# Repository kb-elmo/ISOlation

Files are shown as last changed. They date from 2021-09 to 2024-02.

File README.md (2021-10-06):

# ISOlation

[][cc-by-nc-sa]<a href="https://ko-fi.com/kb_elmo">kofibadge</a>

### A seamless ISO single-key "macropad"
#### Stupid things I come up with during Covid isolation...

header

---

[STEP files for the case](case/)

[KiCAD PCB files](pcb/)

[Gerbers for PCB production](pcb/gerbers/)

[JLCPCB BOM](pcb/fab/iso_bom_jlc.csv)

[JLCPCB CPL](pcb/fab/iso_cpl_jlc.csv)

[Vial-QMK firmware](firmware/)

---

This work is licensed under a
[Creative Commons Attribution-NonCommercial-ShareAlike 4.0 International License][cc-by-nc-sa].

[][cc-by-nc-sa]

[cc-by-nc-sa]: http://creativecommons.org/licenses/by-nc-sa/4.0/
[cc-by-nc-sa-image]: https://licensebuttons.net/l/by-nc-sa/4.0/88x31.png
[cc-by-nc-sa-shield]: https://img.shields.io/badge/License-CC%20BY--NC--SA%204.0-lightgrey.svg

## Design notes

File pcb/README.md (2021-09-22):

# ISOlation PCB

### Features

- Full key and stabilizer RGB
- Screw-in stabilizer support
- Powered by an Atmega328p
- Basic ESD and overvoltage protection
- Centered USB type-C port for a detachable cable
- Fully programmable using [QMK](https://qmk.fm) and [Vial](https://get.vial.today)

---

### Preview

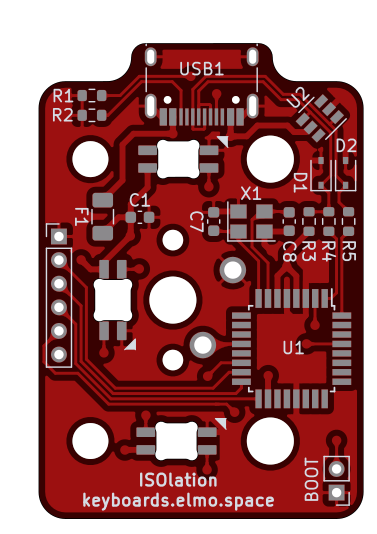
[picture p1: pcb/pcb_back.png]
pcb_back
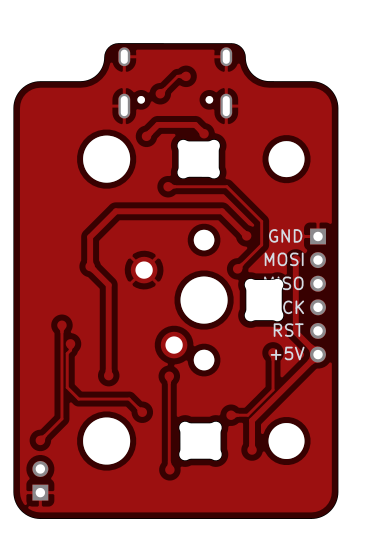
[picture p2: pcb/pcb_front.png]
pcb_front


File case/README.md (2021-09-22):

# ISOlation case

### These files are meant for 3D printing only! 

They are not suitable for CNC machining and trying to use them for that will most likely result in failure of the parts.

The top piece should be printed upside down with supports for the integrated plate to get the best looking results.  
The bottom can be printed without any supports in it's natural orientation.

The bottom part is a simple friction fit into the top.  
Make sure that everything works and is installed properly on the PCB when putting the case together.  
Removing the bottom piece later is not really easy.

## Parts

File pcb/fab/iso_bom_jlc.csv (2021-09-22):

Comment | Designator | Footprint | LCSC Part #
10uF | C1 | C_0603_1608Metric | C19702
22pF | C7,C8 | C_0603_1608Metric | C1653
D_Zener_Small | D2,D1 | D_SOD-323 | C401091
Polyfuse_Small | F1 | Fuse_1206_3216Metric | C69688
5.1k | R1,R2 | R_0603_1608Metric | C23186
1.5K | R3 | R_0603_1608Metric | C22843
68R | R4,R5 | R_0603_1608Metric | C27592
ATmega328P-AU | U1 | TQFP-32_7x7mm_P0.8mm | C14877
SRV05-4 | U2 | SOT-23-6 | C85364
USB_C_Receptacle_USB2.0 | USB1 | USB_C_Receptacle_HRO_TYPE-C-31-M-12 | C165948
Crystal_GND24_Small | X1 | Crystal_SMD_3225-4Pin_3.2x2.5mm | C13738

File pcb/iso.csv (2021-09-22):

Comment | Designator | Footprint | LCSC
SW_Push | BOOT1 | Connector_PinHeader_2.00mm:PinHeader_1x02_P2.00mm_Vertical
10uF | C1 | Capacitor_SMD:C_0603_1608Metric | C19702
22pF | C7,C8 | Capacitor_SMD:C_0603_1608Metric | C1653
D_Zener_Small | D1,D2 | Diode_SMD:D_SOD-323 | C401091
Polyfuse_Small | F1 | Fuse:Fuse_1206_3216Metric | C69688
Conn_01x06 | J1 | Connector_PinHeader_2.00mm:PinHeader_1x06_P2.00mm_Vertical
SK6812MINI | LED1,LED2,LED3 | custom_parts:SK6812MINIE-simple
MX-NoLED | MX1 | custom_parts:MXOnly-ISO-ROTATEDCCW-ReversedStabilizers-NoLED
5.1k | R1,R2 | Resistor_SMD:R_0603_1608Metric | C23186
1.5K | R3 | Resistor_SMD:R_0603_1608Metric | C22843
68R | R4,R5 | Resistor_SMD:R_0603_1608Metric | C27592
ATmega328P-AU | U1 | Package_QFP:TQFP-32_7x7mm_P0.8mm | C14877
SRV05-4 | U2 | Package_TO_SOT_SMD:SOT-23-6 | C85364
USB_C_Receptacle_USB2.0 | USB1 | Connector_USB:USB_C_Receptacle_HRO_TYPE-C-31-M-12 | C165948
Crystal_GND24_Small | X1 | Crystal:Crystal_SMD_3225-4Pin_3.2x2.5mm | C13738

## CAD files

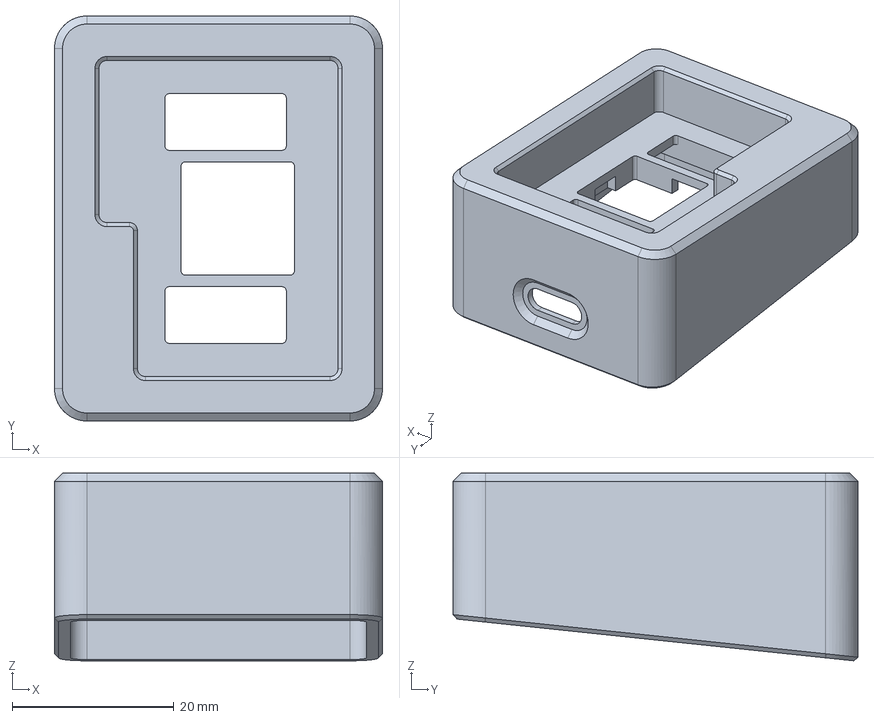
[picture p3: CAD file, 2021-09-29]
case/top.step
40.6 x 50.1 x 23.2 mm

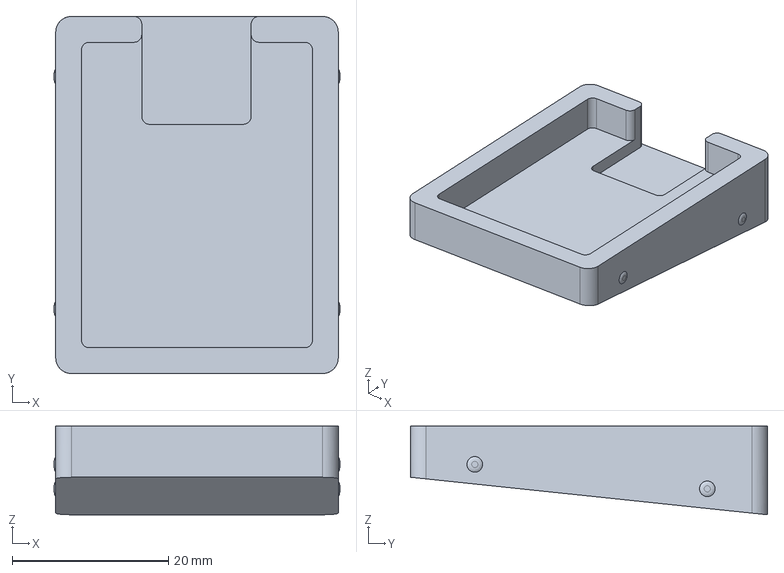
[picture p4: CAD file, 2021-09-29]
case/bottom.step
36.6 x 45.7 x 11.3 mm

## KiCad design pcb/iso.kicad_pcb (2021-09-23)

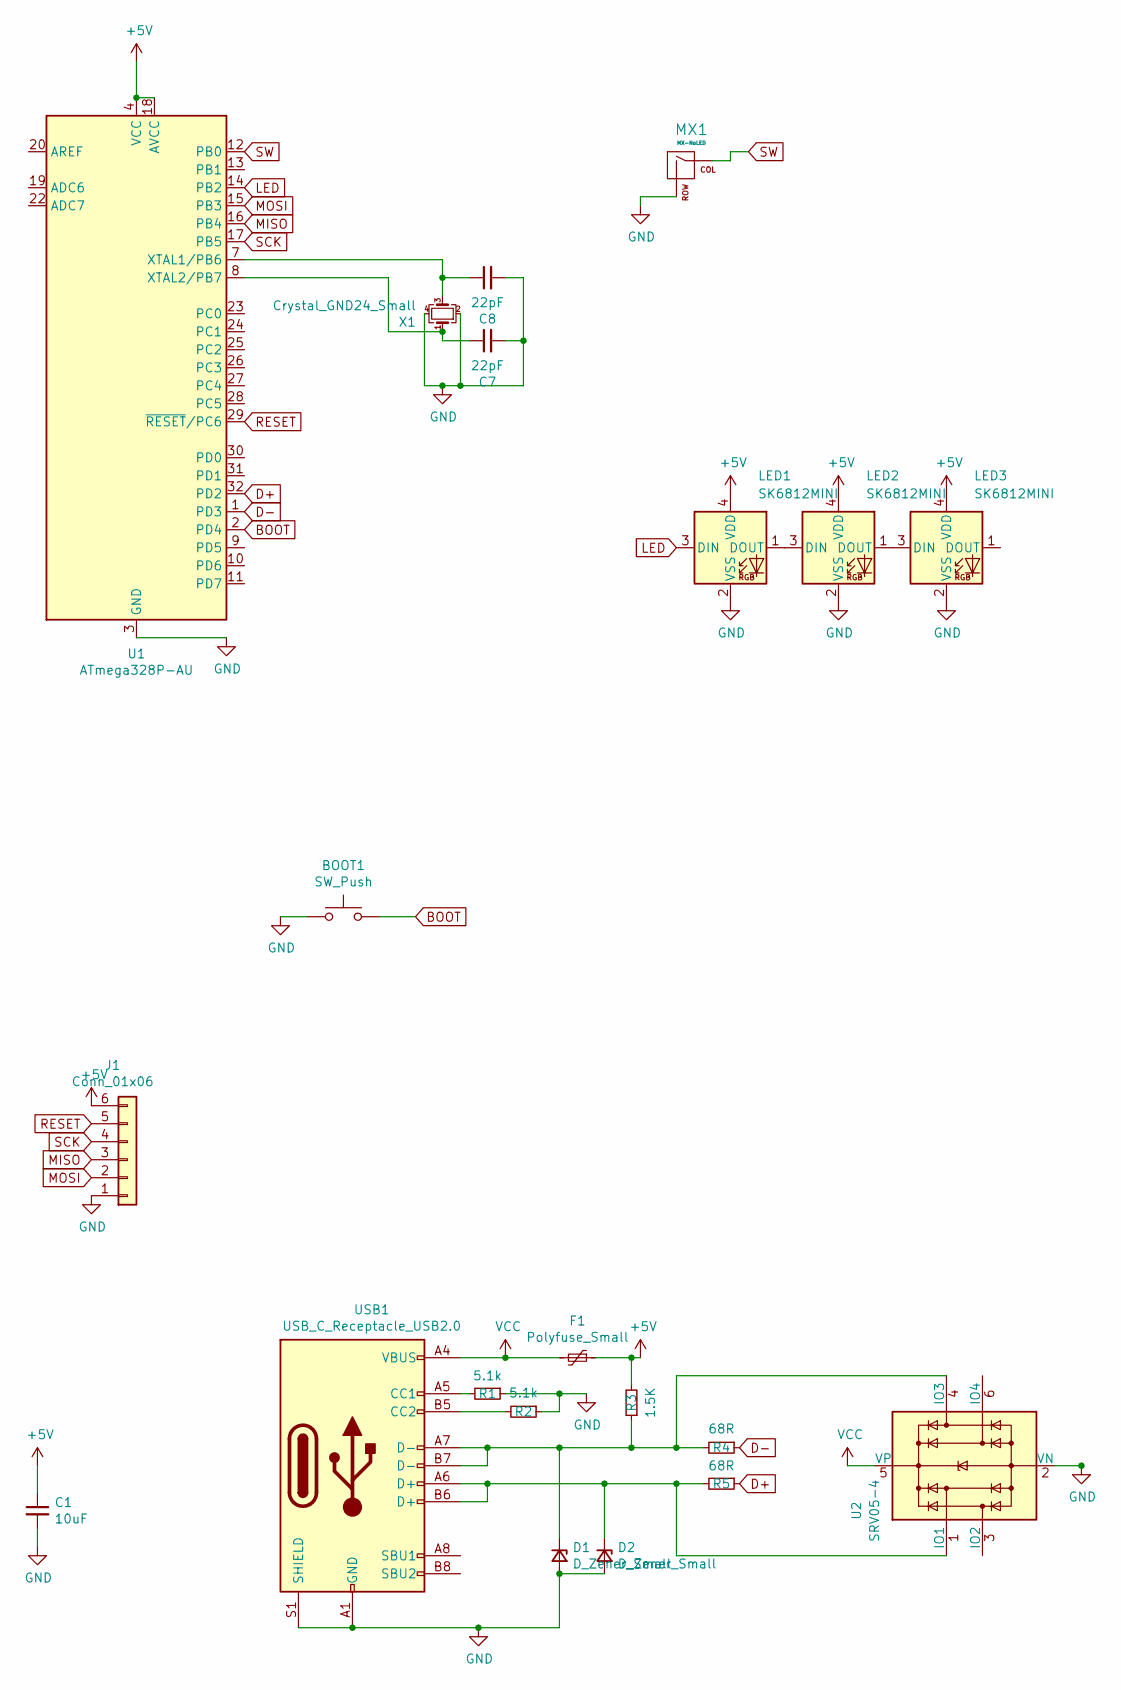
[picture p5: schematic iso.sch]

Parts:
BOOT1: SW_Push; PinHeader_1x02_P2.00mm_Vertical
C1: 10uF; C_0603_1608Metric; LCSC C19702
C7, C8: 22pF; C_0603_1608Metric; LCSC C1653
D1, D2: D_Zener_Small; D_SOD-323; LCSC C401091
F1: Polyfuse_Small; Fuse_1206_3216Metric; LCSC C69688
J1: Conn_01x06; PinHeader_1x06_P2.00mm_Vertical
LED1, LED2, LED3: SK6812MINI; SK6812MINIE-simple
MX1: MX-NoLED; MXOnly-ISO-ROTATEDCCW-ReversedStabilizers-NoLED
R1, R2: 5.1k; R_0603_1608Metric; LCSC C23186
R3: 1.5K; R_0603_1608Metric; LCSC C22843
R4, R5: 68R; R_0603_1608Metric; LCSC C27592
U1: ATmega328P-AU; TQFP-32_7x7mm_P0.8mm; LCSC C14877
U2: SRV05-4; SOT-23-6; LCSC C85364
USB1: USB_C_Receptacle_USB2.0; USB_C_Receptacle_HRO_TYPE-C-31-M-12; LCSC C165948
X1: Crystal_GND24_Small; Crystal_SMD_3225-4Pin_3.2x2.5mm; LCSC C13738

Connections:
+5V: C1.1, F1.1, J1.6, LED1.4 (VDD), LED2.4 (VDD), LED3.4 (VDD), R3.2, U1.4 (VCC), U1.6 (VCC), U1.18 (AVCC)
BOOT: BOOT1.2, U1.2 (PD4); also elsewhere on the board
D+: R5.1, U1.32 (PD2)
D-: R4.1, U1.1 (PD3)
GND: BOOT1.1, C1.2, C7.2, C8.2, D1.2 (A), D2.2 (A), J1.1, LED1.2 (VSS), LED2.2 (VSS), LED3.2 (VSS), MX1.2 (ROW), R1.1, R2.1, U1.3 (GND), U1.5 (GND), U1.21 (GND), U2.2 (VN), USB1.A1 (GND), USB1.A12 (GND), USB1.B1 (GND), USB1.B12 (GND), USB1.S1 (SHIELD), X1.2, X1.4; also elsewhere on the board
LED: LED1.3 (DIN), U1.14 (PB2)
MISO: J1.3, U1.16 (PB4)
MOSI: J1.2, U1.15 (PB3)
unnamed: C7.1, U1.8 (XTAL2/PB7), X1.1
unnamed: C8.1, U1.7 (XTAL1/PB6), X1.3
unnamed: D1.1 (K), R3.1, R4.2, U2.4 (IO3), USB1.A7 (D-), USB1.B7 (D-)
unnamed: D2.1 (K), R5.2, U2.1 (IO1), USB1.A6 (D+), USB1.B6 (D+)
unnamed: LED1.1 (DOUT), LED2.3 (DIN)
unnamed: LED2.1 (DOUT), LED3.3 (DIN)
unnamed: R1.2, USB1.A5 (CC1)
unnamed: R2.2, USB1.B5 (CC2)
RESET: J1.5, U1.29 (~RESET~/PC6)
SCK: J1.4, U1.17 (PB5)
SW: MX1.1 (COL), U1.12 (PB0)
VCC: F1.2, U2.5 (VP), USB1.A4 (VBUS), USB1.A9 (VBUS), USB1.B4 (VBUS), USB1.B9 (VBUS)

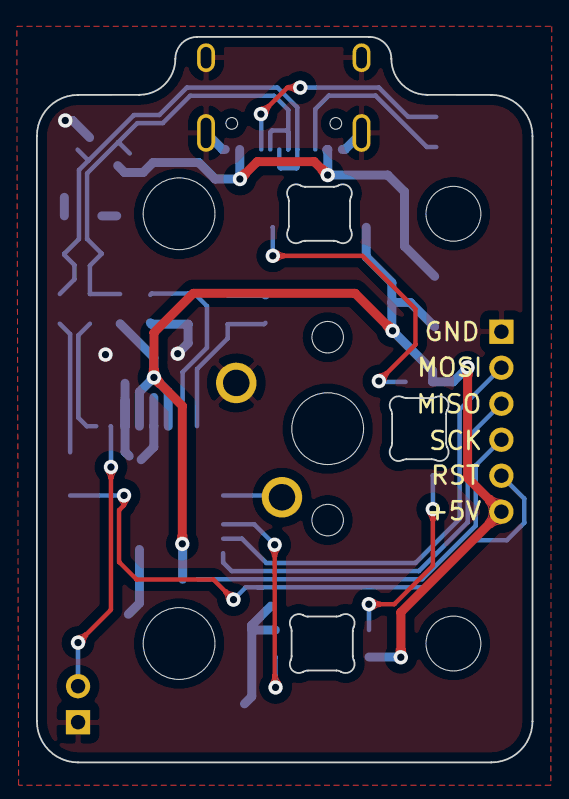
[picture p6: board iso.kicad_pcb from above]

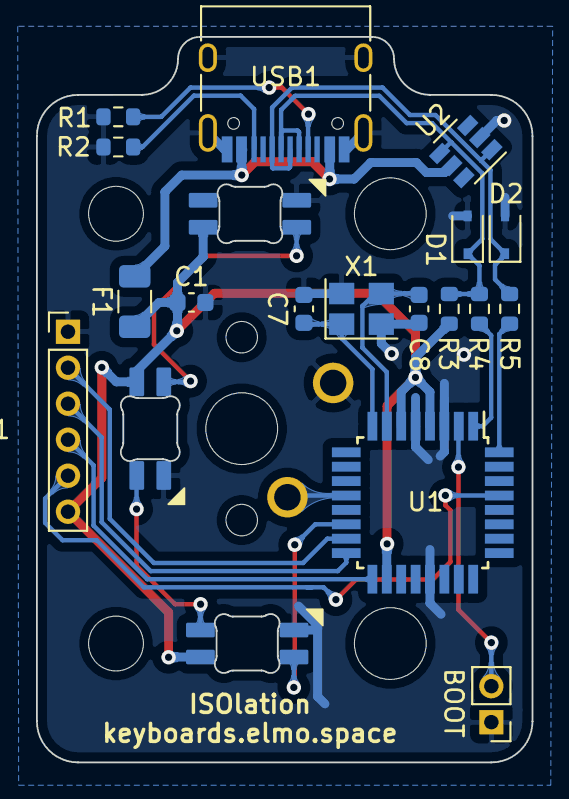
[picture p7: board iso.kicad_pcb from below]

Board: 2 copper layers, 27.5 x 40.3 mm, 21 parts (17 on the bottom side), 20 nets.

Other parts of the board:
BOOT: SW_Push; PinHeader_1x02_P2.00mm_Vertical

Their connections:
BOOT: BOOT.2; also elsewhere on the board
GND: BOOT.1; also elsewhere on the board

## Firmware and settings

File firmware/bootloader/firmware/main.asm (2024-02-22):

main.elf:     file format elf32-avr

SYMBOL TABLE:
00800100 l    d  .data	00000000 .data
00007000 l    d  .text	00000000 .text
00800106 l    d  .bss	00000000 .bss
0080013b l    d  .noinit	00000000 .noinit
00000000 l    d  .comment	00000000 .comment
00000000 l    d  .note.gnu.avr.deviceinfo	00000000 .note.gnu.avr.deviceinfo
00000000 l    d  .debug_aranges	00000000 .debug_aranges
00000000 l    d  .debug_info	00000000 .debug_info
00000000 l    d  .debug_abbrev	00000000 .debug_abbrev
00000000 l    d  .debug_line	00000000 .debug_line
00000000 l    d  .debug_frame	00000000 .debug_frame
00000000 l    d  .debug_str	00000000 .debug_str
00000000 l    d  .debug_line_str	00000000 .debug_line_str
00000000 l    d  .debug_loclists	00000000 .debug_loclists
00000000 l    d  .debug_macro	00000000 .debug_macro
00000000 l    d  .debug_rnglists	00000000 .debug_rnglists
00000000 l    df *ABS*	00000000 main.c
0000003e l       *ABS*	00000000 __SP_H__
0000003d l       *ABS*	00000000 __SP_L__
0000003f l       *ABS*	00000000 __SREG__
00000000 l       *ABS*	00000000 __tmp_reg__
00000001 l       *ABS*	00000000 __zero_reg__
000070e4 l       .text	00000000 .Loc.0
000070e4 l       .text	00000000 L0
000070e4 l       .text	00000000 .Loc.1
000070f4 l       .text	00000000 __BOOTLOADERENTRY_FROMSOFTWARE__bootup_investigate_RAMEND_done6
000070f2 l       .text	00000000 __BOOTLOADERENTRY_FROMSOFTWARE__bootup_investigate_RAMEND_mismatch6
0080013c l     O .noinit	00000001 __BOOTLOADERENTRY_FROMSOFTWARE__bootup_RAMEND_doesmatch
0080013b l     O .noinit	00000001 __BOOTLOADERENTRY_FROMSOFTWARE__bootup_MCUCSR
000070fc l       .text	00000000 .Loc.2
000070fc l       .text	00000000 L0
00007382 l       .text	00000000 .Loc.3
00007382 l       .text	00000000 L0
00007382 l       .text	00000000 .Loc.4
00007384 l       .text	00000000 .Loc.5
00007384 l       .text	00000000 .Loc.6
00007384 l       .text	00000000 .Loc.7
00007384 l       .text	00000000 .Loc.8
00007386 l       .text	00000000 .Loc.9
00007386 l       .text	00000000 .Loc.10
00007388 l       .text	00000000 .Loc.11
0000738c l       .text	00000000 .Loc.12
00007392 l       .text	00000000 .Loc.13
00007392 l       .text	00000000 .Loc.14
00007394 l       .text	00000000 .Loc.15
00007398 l       .text	00000000 .Loc.16
00007398 l       .text	00000000 .Loc.17
00007398 l       .text	00000000 .Loc.18
0000739a l       .text	00000000 .Loc.19
0000739c l       .text	00000000 .Loc.20
0000739e l       .text	00000000 .Loc.21
00800102 l     O .data	00000004 signatureBytes
000073a4 l       .text	00000000 .Loc.22
000073a6 l       .text	00000000 .Loc.23
000073a6 l       .text	00000000 .Loc.24
000073aa l       .text	00000000 .Loc.25
000073b0 l       .text	00000000 .Loc.26
000073b0 l       .text	00000000 .Loc.27
000073b4 l       .text	00000000 .Loc.28
000073b4 l       .text	00000000 .Loc.29
000073ba l       .text	00000000 .Loc.30
000073be l       .text	00000000 .Loc.31
000073c2 l       .text	00000000 .Loc.32
000073c2 l       .text	00000000 .Loc.33
000073c6 l       .text	00000000 .Loc.34
000073ca l       .text	00000000 .Loc.35
000073ca l       .text	00000000 .Loc.36
000073ca l       .text	00000000 .Loc.37
000073d0 l       .text	00000000 .Loc.38
000073d6 l       .text	00000000 .Loc.39
000073d6 l       .text	00000000 .Loc.40
000073d6 l       .text	00000000 .Loc.41
000073d8 l       .text	00000000 .Loc.42
000073d8 l       .text	00000000 .Loc.43
000073dc l       .text	00000000 .Loc.44
000073dc l       .text	00000000 .Loc.45
000073dc l       .text	00000000 .Loc.46
000073e2 l       .text	00000000 .Loc.47
000073e4 l       .text	00000000 .Loc.48
000073e4 l       .text	00000000 .Loc.49
000073e4 l       .text	00000000 .Loc.50
000073e4 l       .text	00000000 .Loc.51
000073e8 l       .text	00000000 .Loc.52
000073e8 l       .text	00000000 .Loc.53
000073e8 l       .text	00000000 .Loc.54
000073e8 l       .text	00000000 .Loc.55
000073ec l       .text	00000000 .Loc.56
000073ee l       .text	00000000 .Loc.57
000073ee l       .text	00000000 .Loc.58
000073f0 l       .text	00000000 .Loc.59
000073f0 l       .text	00000000 .Loc.60
000073f0 l       .text	00000000 .Loc.61
000073f0 l       .text	00000000 .Loc.62
000073f0 l       .text	00000000 .Loc.63
000073f2 l       .text	00000000 .Loc.64
000073f2 l       .text	00000000 .Loc.65
000073f6 l       .text	00000000 .Loc.66
000073f6 l       .text	00000000 .Loc.67
000073f6 l       .text	00000000 .Loc.68
000073f6 l       .text	00000000 .Loc.69
000073fa l       .text	00000000 .Loc.70
000073fc l       .text	00000000 .Loc.71
000073fe l       .text	00000000 .Loc.72
00007400 l       .text	00000000 .Loc.73
00007400 l       .text	00000000 .Loc.74
00007400 l       .text	00000000 .Loc.75
00007404 l       .text	00000000 .Loc.76
00007404 l       .text	00000000 .Loc.77
00007406 l       .text	00000000 .Loc.78
00007406 l       .text	00000000 .Loc.79
0000740a l       .text	00000000 .Loc.80
0000740e l       .text	00000000 .Loc.81
00007410 l       .text	00000000 .Loc.82
00007410 l       .text	00000000 .Loc.83
00007414 l       .text	00000000 .Loc.84
00007414 l       .text	00000000 .Loc.85
00800139 l     O .bss	00000001 stayinloader
0000741c l       .text	00000000 L0
0000741c l       .text	00000000 .Loc.86
0000741c l       .text	00000000 L0
0000741c l       .text	00000000 .Loc.87
0000741c l       .text	00000000 .Loc.88
0000741c l       .text	00000000 .Loc.89
0000741c l       .text	00000000 .Loc.90
0000741e l       .text	00000000 .Loc.91
0000741e l       .text	00000000 .Loc.92
00007422 l       .text	00000000 .Loc.93
00007422 l       .text	00000000 .Loc.94
00007422 l       .text	00000000 .Loc.95
00007422 l       .text	00000000 .Loc.96
00007426 l       .text	00000000 .Loc.97
00007426 l       .text	00000000 .Loc.98
0000742a l       .text	00000000 .Loc.99
0000742a l       .text	00000000 .Loc.100
0000742a l       .text	00000000 .Loc.101
0000742e l       .text	00000000 _mywait_sleeploop252
00007436 l       .text	00000000 .Loc.102
00007436 l       .text	00000000 .Loc.103
00007436 l       .text	00000000 .Loc.104
00007436 l       .text	00000000 .Loc.105
00007436 l       .text	00000000 .Loc.106
0000743c l       .text	00000000 .Loc.107
00007440 l       .text	00000000 .Loc.108
00007440 l       .text	00000000 .Loc.109
00007444 l       .text	00000000 .Loc.110
00007448 l       .text	00000000 .Loc.111
00007448 l       .text	00000000 .Loc.112
0000744c l       .text	00000000 .Loc.113
0000744c l       .text	00000000 .Loc.114
0000744c l       .text	00000000 .Loc.115
0000744c l       .text	00000000 .Loc.116
0000744e l       .text	00000000 .Loc.117
00007450 l       .text	00000000 .Loc.118
00007450 l       .text	00000000 .Loc.119
00007450 l       .text	00000000 .Loc.120
00007450 l       .text	00000000 .Loc.121
00007452 l       .text	00000000 .Loc.122
00007452 l       .text	00000000 .Loc.123
00007454 l       .text	00000000 .Loc.124
00007454 l       .text	00000000 .Loc.125
00007458 l       .text	00000000 .Loc.126
00007458 l       .text	00000000 .Loc.127
0000745c l       .text	00000000 .Loc.128
0000745c l       .text	00000000 .Loc.129
0000745e l       .text	00000000 .Loc.130
00007464 l       .text	00000000 .Loc.131
00007464 l       .text	00000000 .Loc.132
0000746a l       .text	00000000 .Loc.133
0000746a l       .text	00000000 .Loc.134
0000746c l       .text	00000000 .Loc.135
0000746c l       .text	00000000 .Loc.136
0000746c l       .text	00000000 .Loc.137
0000746c l       .text	00000000 .Loc.138
0000746c l       .text	00000000 .Loc.139
00007482 l       .text	00000000 .Loc.140
00007482 l       .text	00000000 .Loc.141
00007482 l       .text	00000000 .Loc.142
00007482 l       .text	00000000 .Loc.143
00007482 l       .text	00000000 .Loc.144
00007486 l       .text	00000000 .Loc.145
0000748c l       .text	00000000 .Loc.146
0000748c l       .text	00000000 .Loc.147
0000748e l       .text	00000000 .Loc.148
0000748e l       .text	00000000 .Loc.149
00007490 l       .text	00000000 .Loc.150
00007490 l       .text	00000000 .Loc.151
00007490 l       .text	00000000 .Loc.152
00007496 l       .text	00000000 _mywait_sleeploop365
0000749e l       .text	00000000 .Loc.153
0000749e l       .text	00000000 .Loc.154
000074a0 l       .text	00000000 .Loc.155
000074a2 l       .text	00000000 .Loc.156
000074a2 l       .text	00000000 .Loc.157
000074a2 l       .text	00000000 .Loc.158
000074a2 l       .text	00000000 .Loc.159
000074a2 l       .text	00000000 .Loc.160
000074a2 l       .text	00000000 .Loc.161
000074a2 l       .text	00000000 .Loc.162
000074a8 l       .text	00000000 .Loc.163
000074a8 l       .text	00000000 .Loc.164
000074ac l       .text	00000000 .Loc.165
000074ac l       .text	00000000 .Loc.166
000074b8 l       .text	00000000 .Loc.167
000074bc l       .text	00000000 .Loc.168
000074bc l       .text	00000000 .Loc.169
000074bc l       .text	00000000 .Loc.170
000074bc l       .text	00000000 .Loc.171
000074bc l       .text	00000000 .Loc.172
000074c4 l       .text	00000000 L0
000074c6 l       .text	00000000 .Loc.173
000074c6 l       .text	00000000 .Loc.174
000074ca l       .text	00000000 L0
000074cc l       .text	00000000 .Loc.175
000074cc l       .text	00000000 .Loc.176
000074cc l       .text	00000000 .Loc.177
000074d2 l       .text	00000000 .Loc.178
000074d2 l       .text	00000000 .Loc.179
000074d8 l       .text	00000000 .Loc.180
000074d8 l       .text	00000000 .Loc.181
0080013a l     O .bss	00000001 usbMsgFlags
000074dc l       .text	00000000 .Loc.182
000074dc l       .text	00000000 .Loc.183
000074de l       .text	00000000 .Loc.184
000074e2 l       .text	00000000 .Loc.185
000074e2 l       .text	00000000 .Loc.186
000074e4 l       .text	00000000 .Loc.187
000074e8 l       .text	00000000 L0
000074ea l       .text	00000000 .Loc.188
000074ea l       .text	00000000 .Loc.189
000074ea l       .text	00000000 .Loc.190
000074ea l       .text	00000000 .Loc.191
000074ea l       .text	00000000 .Loc.192
000074ea l       .text	00000000 .Loc.193
000074ea l       .text	00000000 .Loc.194
00800130 l     O .bss	00000004 replyBuffer.0
000074f6 l       .text	00000000 .Loc.195
000074f6 l       .text	00000000 .Loc.196
000074fa l       .text	00000000 .Loc.197
000074fa l       .text	00000000 .Loc.198
000074fc l       .text	00000000 .Loc.199
000074fe l       .text	00000000 .Loc.200
00007502 l       .text	00000000 .Loc.201
00007502 l       .text	00000000 .Loc.202
00007502 l       .text	00000000 .Loc.203
00007502 l       .text	00000000 .Loc.204
00007504 l       .text	00000000 .Loc.205
00007504 l       .text	00000000 .Loc.206
00007504 l       .text	00000000 .Loc.207
00007504 l       .text	00000000 .Loc.208
0000750a l       .text	00000000 .Loc.209
00007514 l       .text	00000000 .Loc.210
00007514 l       .text	00000000 .Loc.211
00007518 l       .text	00000000 L0
0000751a l       .text	00000000 .Loc.212
0000751e l       .text	00000000 L0
00007520 l       .text	00000000 .Loc.213
00007520 l       .text	00000000 .Loc.214
00007522 l       .text	00000000 .Loc.215
00007524 l       .text	00000000 .Loc.216
00007528 l       .text	00000000 L0
0000752a l       .text	00000000 .Loc.217
0000752a l       .text	00000000 .Loc.218
00800137 l     O .bss	00000002 currentAddress
00007536 l       .text	00000000 .Loc.219
00007536 l       .text	00000000 .Loc.220
0000753a l       .text	00000000 L0
0000753c l       .text	00000000 .Loc.221
0000753c l       .text	00000000 .Loc.222
0000753e l       .text	00000000 .Loc.223
00800136 l     O .bss	00000001 bytesRemaining
00007542 l       .text	00000000 .Loc.224
00007542 l       .text	00000000 .Loc.225
00007546 l       .text	00000000 .Loc.226
00800135 l     O .bss	00000001 isLastPage
0000754a l       .text	00000000 .Loc.227
0000754a l       .text	00000000 .Loc.228
00800134 l     O .bss	00000001 currentRequest
0000754e l       .text	00000000 .Loc.229
0000754e l       .text	00000000 .Loc.230
0000754e l       .text	00000000 .Loc.231
0000754e l       .text	00000000 .Loc.232
0000754e l       .text	00000000 .Loc.233
00007552 l       .text	00000000 .Loc.234
00007552 l       .text	00000000 .Loc.235
00007558 l       .text	00000000 .Loc.236
00007558 l       .text	00000000 .Loc.237
00800100 l     O .data	00000001 usbMsgLen
0000755c l       .text	00000000 .Loc.238
0000755c l       .text	00000000 .Loc.239
0000755c l       .text	00000000 .Loc.240
00007560 l       .text	00000000 .Loc.241
00007560 l       .text	00000000 .Loc.242
00007564 l       .text	00000000 .Loc.243
00007568 l       .text	00000000 .Loc.244
00007568 l       .text	00000000 .Loc.245
0000756c l       .text	00000000 .Loc.246
00007570 l       .text	00000000 .Loc.247
00007570 l       .text	00000000 .Loc.248
00007570 l       .text	00000000 .Loc.249
00007570 l       .text	00000000 .Loc.250
00007570 l       .text	00000000 .Loc.251
00007570 l       .text	00000000 .Loc.252
00007570 l       .text	00000000 .Loc.253
00007578 l       .text	00000000 .Loc.254
00007578 l       .text	00000000 .Loc.255
00007580 l       .text	00000000 .Loc.256
00007580 l       .text	00000000 .Loc.257
0000758c l       .text	00000000 .Loc.258
0000758c l       .text	00000000 .Loc.259
0000758c l       .text	00000000 .Loc.260
0000758c l       .text	00000000 .Loc.261
00007590 l       .text	00000000 .Loc.262
00007590 l       .text	00000000 .Loc.263
00007594 l       .text	00000000 .Loc.264
00007598 l       .text	00000000 .Loc.265
00007598 l       .text	00000000 .Loc.266
00007598 l       .text	00000000 .Loc.267
00007598 l       .text	00000000 .Loc.268
00007598 l       .text	00000000 .Loc.269
0000759c l       .text	00000000 .Loc.270
000075a4 l       .text	00000000 .Loc.271
000075a4 l       .text	00000000 .Loc.272
000075aa l       .text	00000000 .Loc.273
000075aa l       .text	00000000 .Loc.274
000075ae l       .text	00000000 .Loc.275
000075b0 l       .text	00000000 .Loc.276
000075b8 l       .text	00000000 .Loc.277
000075bc l       .text	00000000 .Loc.278
000075bc l       .text	00000000 .Loc.279
000075c4 l       .text	00000000 .Loc.280
000075c4 l       .text	00000000 .Loc.281
000075c8 l       .text	00000000 .Loc.282
000075c8 l       .text	00000000 .Loc.283
000075cc l       .text	00000000 .Loc.284
000075cc l       .text	00000000 .Loc.285
000075d2 l       .text	00000000 .Loc.286
000075d2 l       .text	00000000 .Loc.287
000075d6 l       .text	00000000 .Loc.288
000075d6 l       .text	00000000 .Loc.289
000075d6 l       .text	00000000 .Loc.290
000075d6 l       .text	00000000 .Loc.291
000075d6 l       .text	00000000 .Loc.292
000075d8 l       .text	00000000 .Loc.293
000075d8 l       .text	00000000 .Loc.294
000075d8 l       .text	00000000 .Loc.295
000075da l       .text	00000000 .Loc.296
000075da l       .text	00000000 .Loc.297
000075dc l       .text	00000000 .Loc.298
000075e0 l       .text	00000000 .Loc.299
000075e0 l       .text	00000000 .Loc.300
000075e2 l       .text	00000000 .Loc.301
000075e4 l       .text	00000000 .Loc.302
000075e4 l       .text	00000000 .Loc.303
000075e8 l       .text	00000000 .Loc.304
000075e8 l       .text	00000000 .Loc.305
000075ec l       .text	00000000 .Loc.306
000075ec l       .text	00000000 .Loc.307
000075ec l       .text	00000000 .Loc.308
000075ec l       .text	00000000 .Loc.309
000075ec l       .text	00000000 .Loc.310
000075ec l       .text	00000000 .Loc.311
000075ec l       .text	00000000 .Loc.312
000075ec l       .text	00000000 .Loc.313
000075ec l       .text	00000000 .Loc.314
000075f0 l       .text	00000000 .Loc.315
000075f4 l       .text	00000000 L0
000075f6 l       .text	00000000 .Loc.316
000075f6 l       .text	00000000 .Loc.317
000075fa l       .text	00000000 .Loc.318
000075fa l       .text	00000000 .Loc.319
00007600 l       .text	00000000 .Loc.320
00007604 l       .text	00000000 .Loc.321
0000760e l       .text	00000000 .Loc.322
0000760e l       .text	00000000 .Loc.323
00007612 l       .text	00000000 .Loc.324
00007616 l       .text	00000000 .Loc.325
00007616 l       .text	00000000 .Loc.326
00007618 l       .text	00000000 .Loc.327
0000761c l       .text	00000000 .Loc.328
0000761c l       .text	00000000 .Loc.329
0000761c l       .text	00000000 .Loc.330
00007620 l       .text	00000000 .Loc.331
00007620 l       .text	00000000 .Loc.332
00007624 l       .text	00000000 .Loc.333
00007624 l       .text	00000000 .Loc.334
00007624 l       .text	00000000 .Loc.335
00007624 l       .text	00000000 .Loc.336
00007624 l       .text	00000000 .Loc.337
00007624 l       .text	00000000 .Loc.338
00007624 l       .text	00000000 .Loc.339
00007626 l       .text	00000000 .Loc.340
00007626 l       .text	00000000 .Loc.341
0000762a l       .text	00000000 .Loc.342
0000762a l       .text	00000000 .Loc.343
0000762a l       .text	00000000 .Loc.344
0000762e l       .text	00000000 .Loc.345
0000762e l       .text	00000000 .Loc.346
0000762e l       .text	00000000 .Loc.347
0000762e l       .text	00000000 .Loc.348
00007632 l       .text	00000000 .Loc.349
00007632 l       .text	00000000 .Loc.350
00007632 l       .text	00000000 .Loc.351
00007636 l       .text	00000000 .Loc.352
00007638 l       .text	00000000 .Loc.353
00007638 l       .text	00000000 .Loc.354
00007638 l       .text	00000000 .Loc.355
00007638 l       .text	00000000 .Loc.356
00007640 l       .text	00000000 .Loc.357
00007640 l       .text	00000000 .Loc.358
00007642 l       .text	00000000 .Loc.359
00007646 l       .text	00000000 .Loc.360
00007646 l       .text	00000000 .Loc.361
0000764a l       .text	00000000 .Loc.362
0000764a l       .text	00000000 .Loc.363
0000764a l       .text	00000000 .Loc.364
0000764e l       .text	00000000 .Loc.365
00007650 l       .text	00000000 .Loc.366
00007654 l       .text	00000000 .Loc.367
00007656 l       .text	00000000 .Loc.368
00007656 l       .text	00000000 .Loc.369
00007656 l       .text	00000000 .Loc.370
00007656 l       .text	00000000 .Loc.371
00007656 l       .text	00000000 .Loc.372
00007656 l       .text	00000000 .Loc.373
0000765a l       .text	00000000 .Loc.374
0000765a l       .text	00000000 .Loc.375
0000765a l       .text	00000000 .Loc.376
0000765a l       .text	00000000 .Loc.377
0000765a l       .text	00000000 .Loc.378
0000765e l       .text	00000000 .Loc.379
00007666 l       .text	00000000 .Loc.380
00007668 l       .text	00000000 .Loc.381
00007668 l       .text	00000000 .Loc.382
00007668 l       .text	00000000 .Loc.383
0000766a l       .text	00000000 .Loc.384
0000766e l       .text	00000000 .Loc.385
0000766e l       .text	00000000 .Loc.386
0000766e l       .text	00000000 .Loc.387
0000766e l       .text	00000000 .Loc.388
0000766e l       .text	00000000 .Loc.389
00007670 l       .text	00000000 .Loc.390
00007674 l       .text	00000000 .Loc.391
00007674 l       .text	00000000 .Loc.392
00007674 l       .text	00000000 .Loc.393
00007674 l       .text	00000000 .Loc.394
00007674 l       .text	00000000 .Loc.395
00007678 l       .text	00000000 .Loc.396
0000767a l       .text	00000000 .Loc.397
0000767e l       .text	00000000 .Loc.398
0000767e l       .text	00000000 .Loc.399
0000767e l       .text	00000000 .Loc.400
00007682 l       .text	00000000 .Loc.401
00007682 l       .text	00000000 .Loc.402
00007682 l       .text	00000000 .Loc.403
00007682 l       .text	00000000 .Loc.404
00007682 l       .text	00000000 .Loc.405
00007686 l       .text	00000000 .Loc.406
00007692 l       .text	00000000 .Loc.407
00007696 l       .text	00000000 .Loc.408
00007696 l       .text	00000000 .Loc.409
00007696 l       .text	00000000 .Loc.410
00007696 l       .text	00000000 .Loc.411
00007696 l       .text	00000000 .Loc.412
0000769a l       .text	00000000 .Loc.413
000076a6 l       .text	00000000 .Loc.414
000076aa l       .text	00000000 .Loc.415
000076aa l       .text	00000000 .Loc.416
000076aa l       .text	00000000 .Loc.417
000076aa l       .text	00000000 .Loc.418
000076aa l       .text	00000000 .Loc.419
000076ae l       .text	00000000 .Loc.420
000076ba l       .text	00000000 .Loc.421
000076ba l       .text	00000000 .Loc.422
000076be l       .text	00000000 .Loc.423
000076c2 l       .text	00000000 .Loc.424
000076c2 l       .text	00000000 .Loc.425
000076c6 l       .text	00000000 .Loc.426
000076c6 l       .text	00000000 .Loc.427
000076c6 l       .text	00000000 .Loc.428
000076c8 l       .text	00000000 .Loc.429
000076c8 l       .text	00000000 .Loc.430
000076ca l       .text	00000000 .Loc.431
000076ce l       .text	00000000 L0
000076d4 l       .text	00000000 .Loc.432
000076d8 l       .text	00000000 .Loc.433
000076da l       .text	00000000 .Loc.434
000076dc l       .text	00000000 .Loc.435
000076dc l       .text	00000000 .Loc.436
000076de l       .text	00000000 .Loc.437
000076e0 l       .text	00000000 .Loc.438
000076e0 l       .text	00000000 .Loc.439
000076e0 l       .text	00000000 .Loc.440
000076e8 l       .text	00000000 .Loc.441
000076e8 l       .text	00000000 .Loc.442
000076e8 l       .text	00000000 .Loc.443
000076e8 l       .text	00000000 .Loc.444
000076e8 l       .text	00000000 .Loc.445
000076e8 l       .text	00000000 .Loc.446
000076ec l       .text	00000000 .Loc.447
000076f2 l       .text	00000000 .Loc.448
000076f2 l       .text	00000000 .Loc.449
000076f8 l       .text	00000000 .Loc.450
000076f8 l       .text	00000000 .Loc.451
000076f8 l       .text	00000000 .Loc.452
000076fa l       .text	00000000 .Loc.453
000076fa l       .text	00000000 .Loc.454
000076fe l       .text	00000000 .Loc.455
000076fe l       .text	00000000 .Loc.456
000076fe l       .text	00000000 .Loc.457
000076fe l       .text	00000000 .Loc.458
00007702 l       .text	00000000 .Loc.459
00007702 l       .text	00000000 .Loc.460
00007708 l       .text	00000000 .Loc.461
00007708 l       .text	00000000 .Loc.462
00007710 l       .text	00000000 .Loc.463
00007718 l       .text	00000000 .Loc.464
00007718 l       .text	00000000 .Loc.465
0000771a l       .text	00000000 .Loc.466
00007728 l       .text	00000000 .Loc.467
0000772a l       .text	00000000 .Loc.468
0000772a l       .text	00000000 .Loc.469
0000772c l       .text	00000000 .Loc.470
0000772e l       .text	00000000 .Loc.471
0000772e l       .text	00000000 .Loc.472
00007734 l       .text	00000000 .Loc.473
00007734 l       .text	00000000 .Loc.474
00007738 l       .text	00000000 .Loc.475
00007738 l       .text	00000000 .Loc.476
0000773a l       .text	00000000 .Loc.477
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

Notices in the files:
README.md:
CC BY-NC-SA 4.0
